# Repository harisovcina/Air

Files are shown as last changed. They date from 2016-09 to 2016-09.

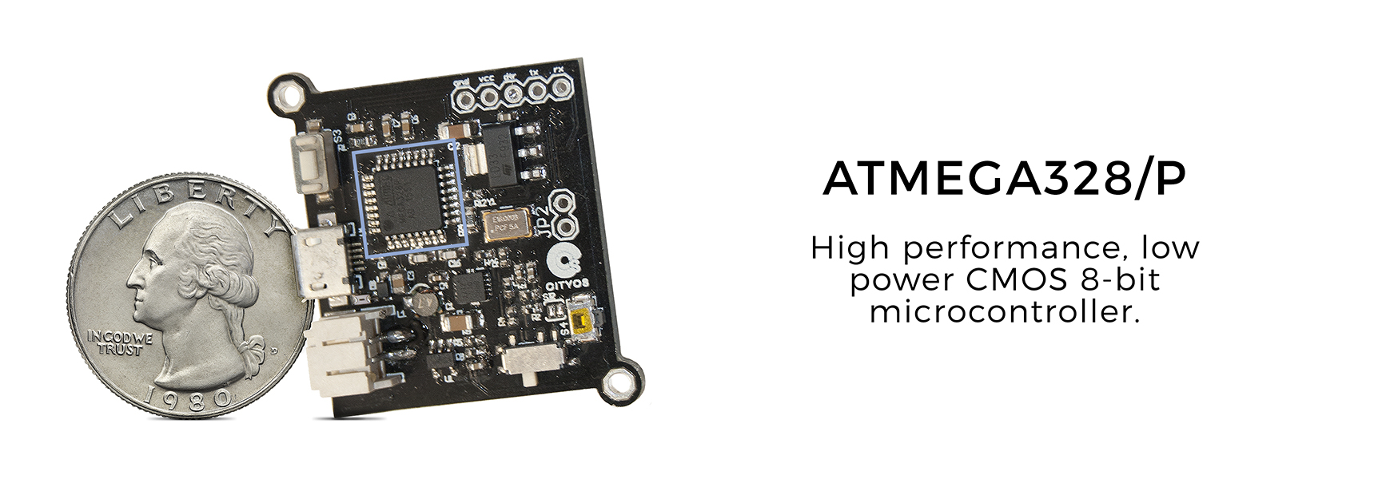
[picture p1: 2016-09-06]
Hardware/Wiki/CPU_back.jpg

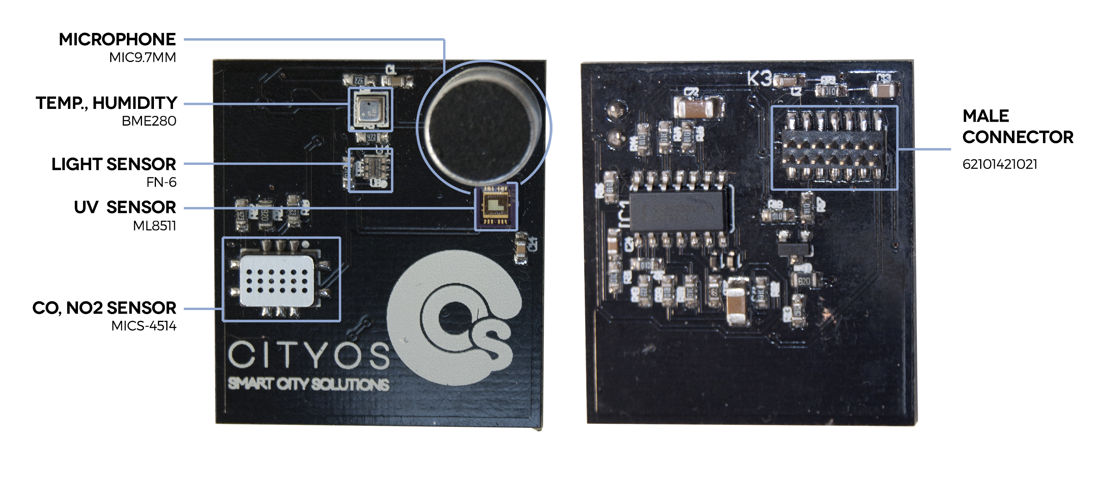
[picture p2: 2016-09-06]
Hardware/Sensor Board/sensor board.jpg

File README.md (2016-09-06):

# CityOSAir

W**elcome to the CityOSAir github!**



Thank you for your interest in creating your own CityOSAir device. In order to join the clean air movement, we will walk you through this step-by-step guide on creating your own device.

Here you will learn how to create your own circuit board or order already made ones, how and where to get an enclosure for the device and, finally, how to setup your new device.

To help spread clean air everywhere, we are giving away all of our code as open source software and hardware. We invite all developers to collaborate and build upon our project. 
Everything you need to get started and become a part of our global movement is listed below.

## Getting started

* [Ordering your board](https://github.com/appsmonkey/CityOSAir/wiki/Board)

* [3D printing your enclosure] (https://github.com/appsmonkey/CityOSAir/wiki/Enclosure)

* [Setting up the device] (https://github.com/appsmonkey/CityOSAir/wiki/Setup)

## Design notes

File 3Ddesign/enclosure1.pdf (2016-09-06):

### 1.Mainboard+sensorboard

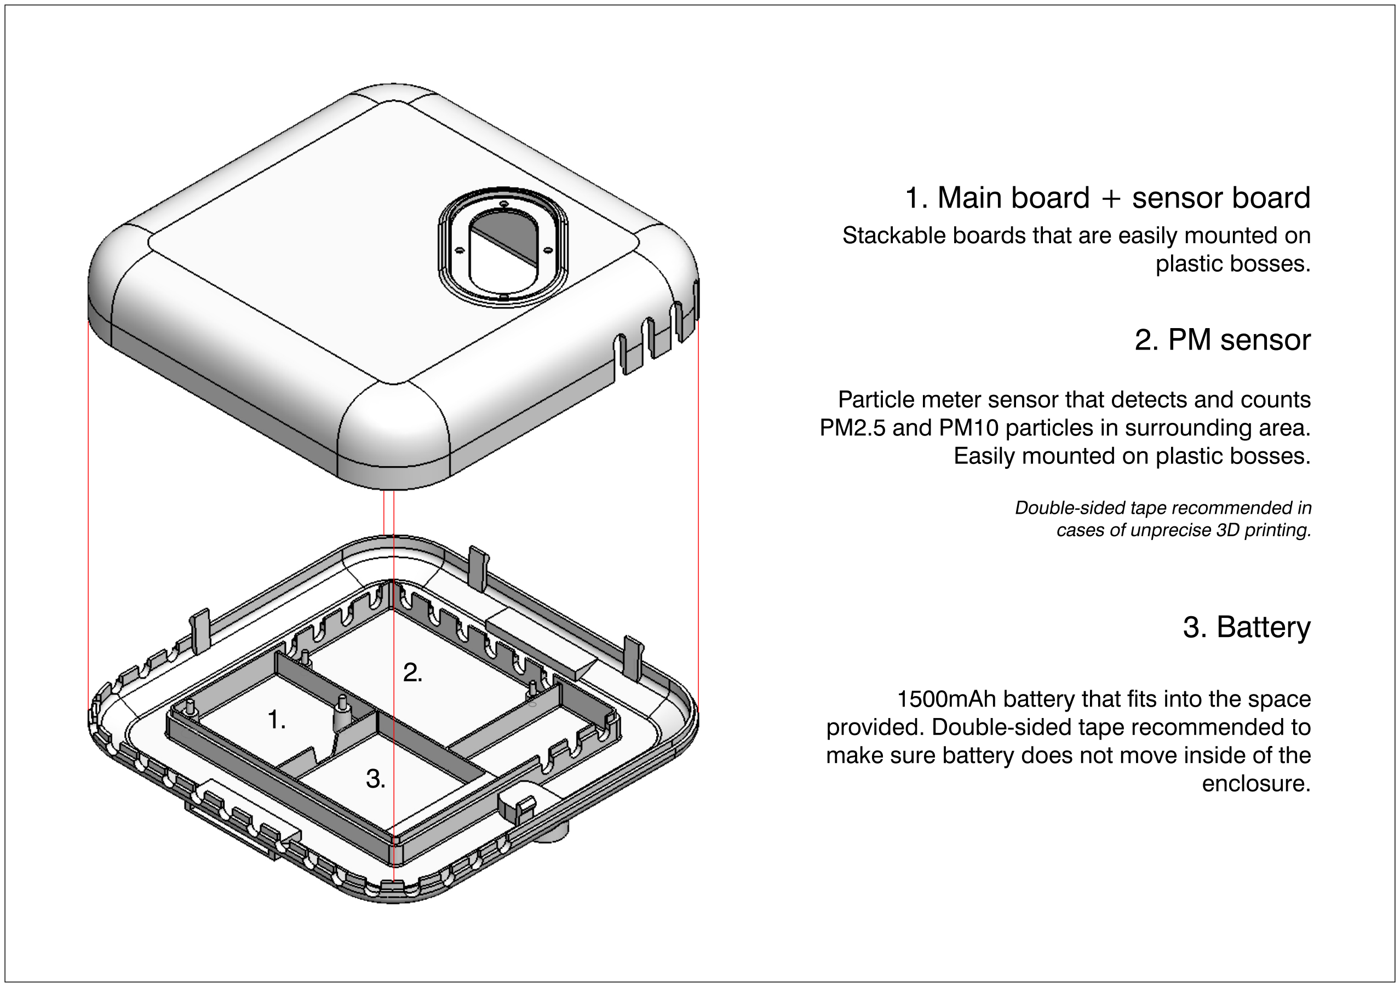
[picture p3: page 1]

1.

2.

3.

### 2.PMsensor

### 3.Battery

Stackableboardsthatareeasilymountedon plasticbosses.

1500mAhbatterythatfitsintothespace provided.Double-sidedtaperecommendedto makesurebatterydoesnotmoveinsideofthe enclosure.

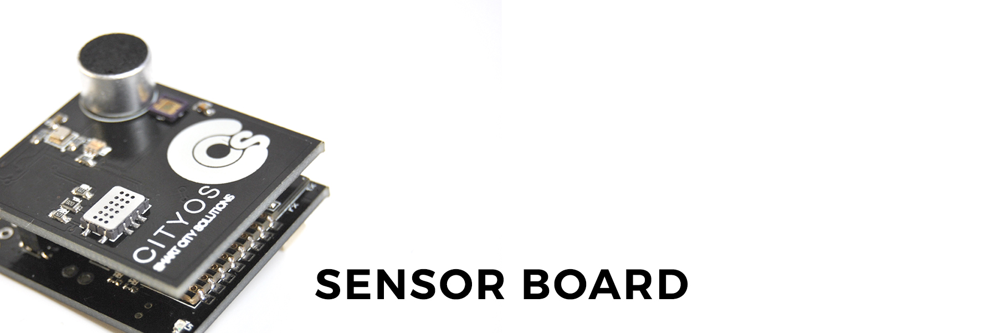
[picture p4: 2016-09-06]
Hardware/Wiki/Header-pic/sensorboard_header.jpg

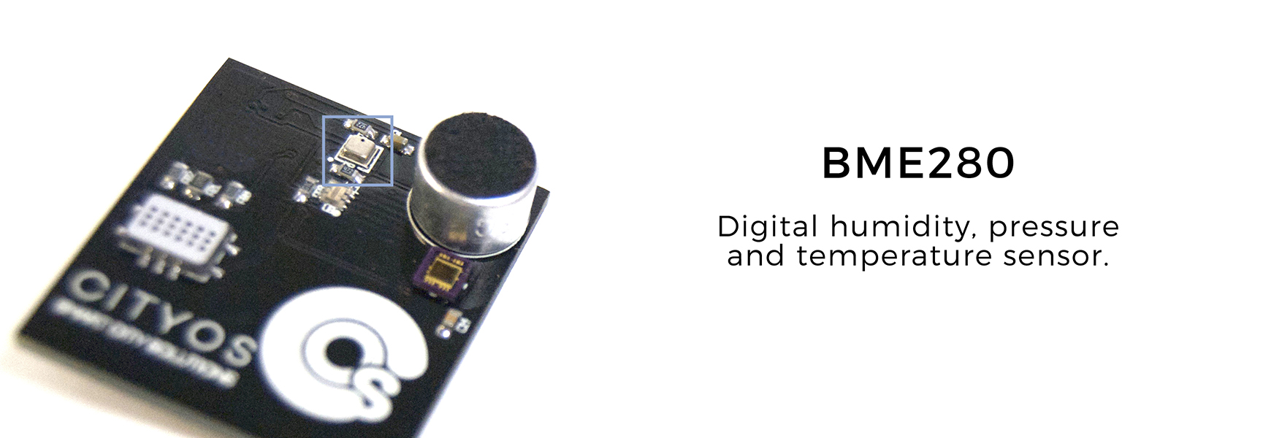
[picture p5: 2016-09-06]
Hardware/Wiki/temp_humid_back.jpg

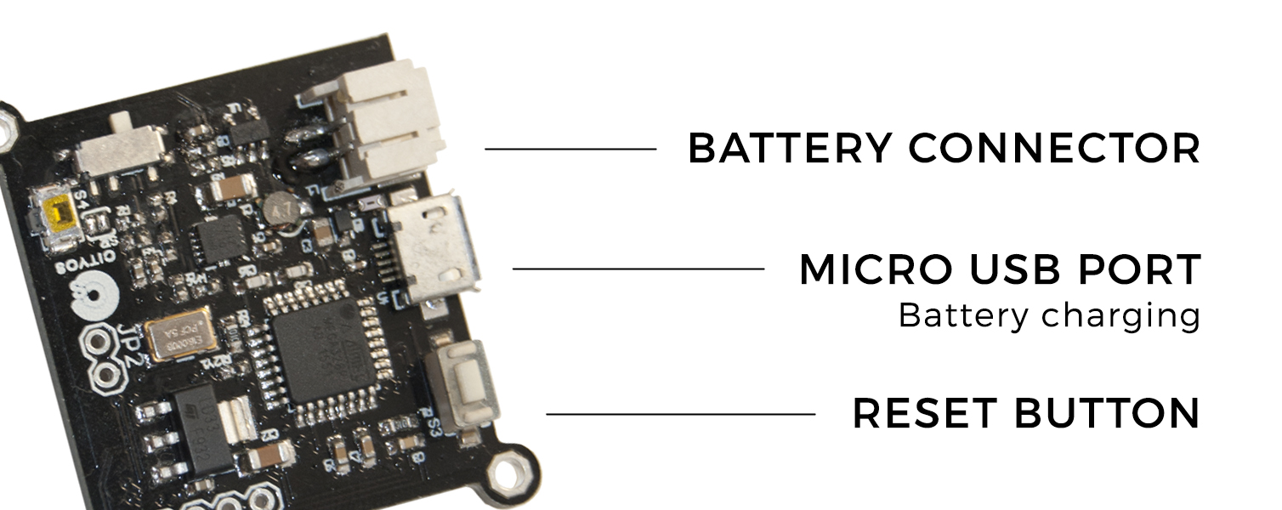
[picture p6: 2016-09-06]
Hardware/Wiki/battery_usb_header.jpg

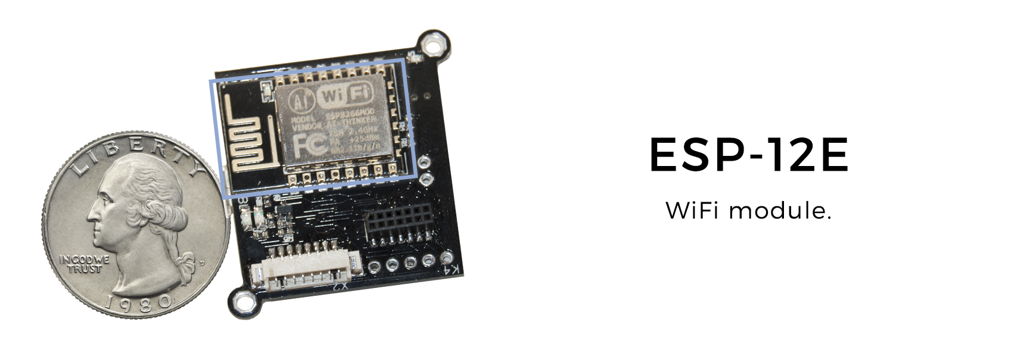
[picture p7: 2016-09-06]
Hardware/Wiki/esp_back.jpg

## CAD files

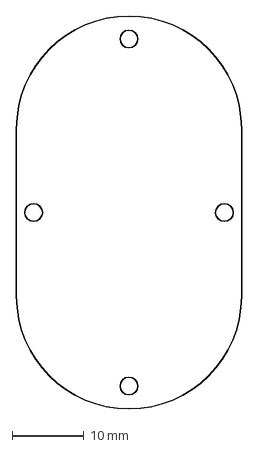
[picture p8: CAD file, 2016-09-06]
3Ddesign/pleksi1.dxf
31.4 x 54.8 mm

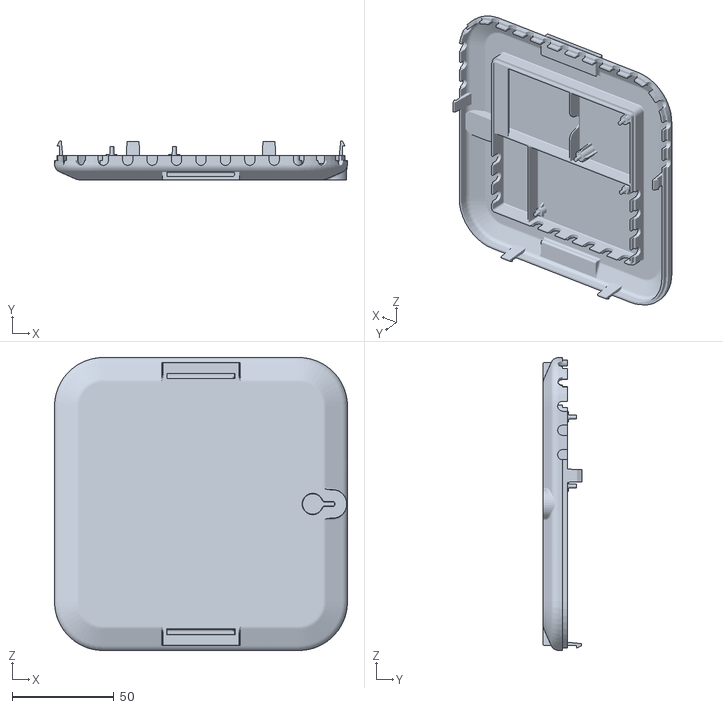
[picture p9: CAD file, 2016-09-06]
3Ddesign/BottomPart1.STL
144.0 x 19.0 x 144.0

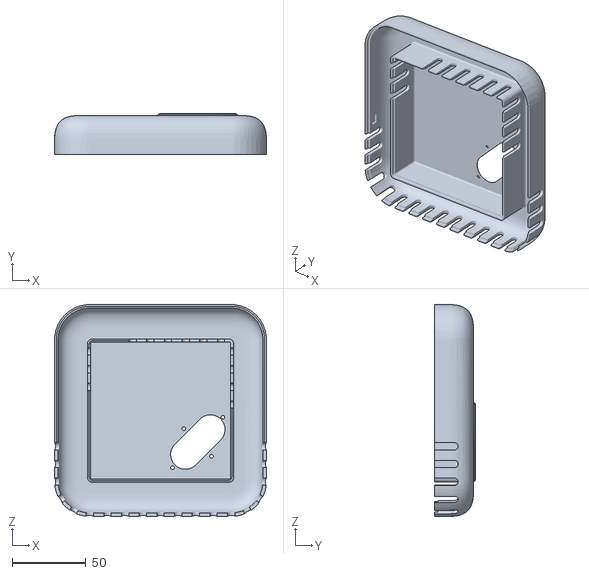
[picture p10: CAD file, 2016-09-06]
3Ddesign/NewTopPart1.STL
144.0 x 27.6 x 144.0

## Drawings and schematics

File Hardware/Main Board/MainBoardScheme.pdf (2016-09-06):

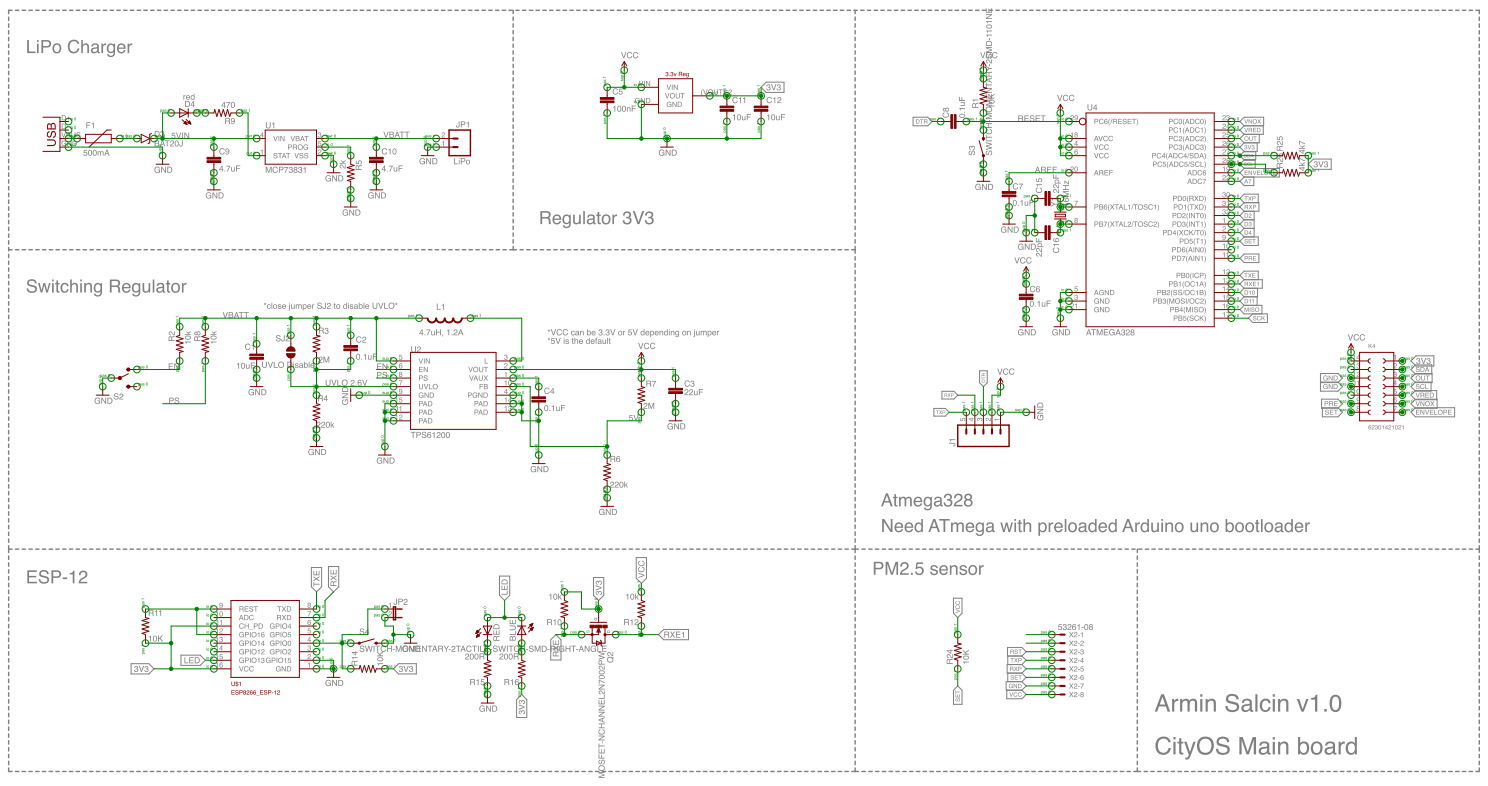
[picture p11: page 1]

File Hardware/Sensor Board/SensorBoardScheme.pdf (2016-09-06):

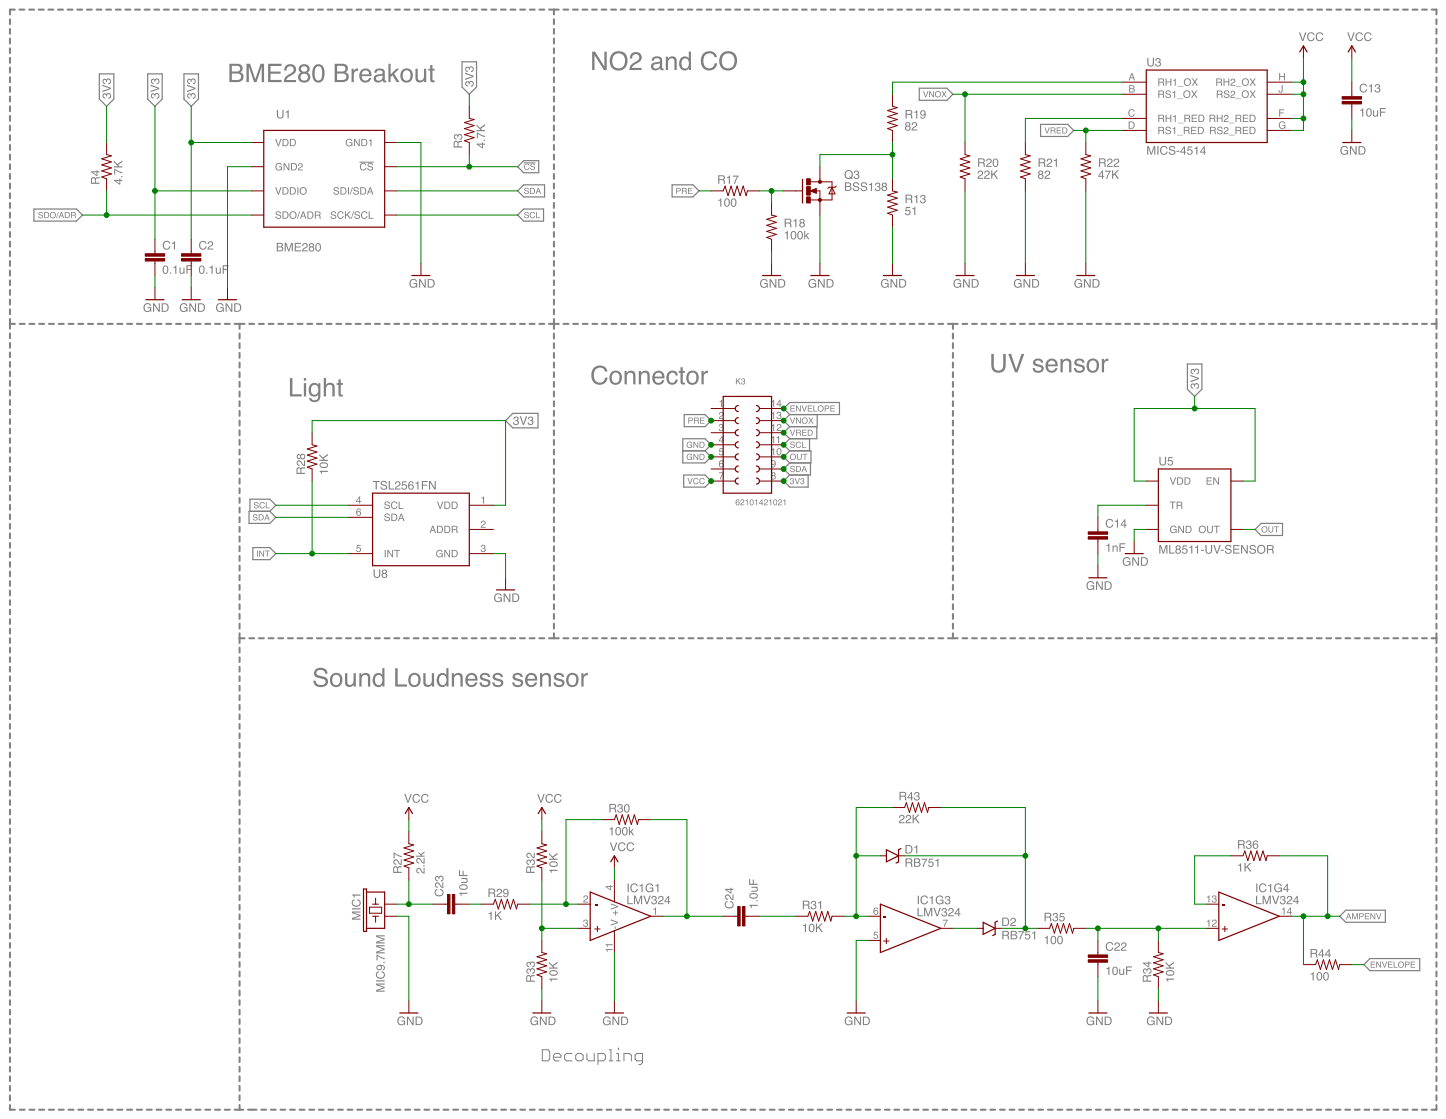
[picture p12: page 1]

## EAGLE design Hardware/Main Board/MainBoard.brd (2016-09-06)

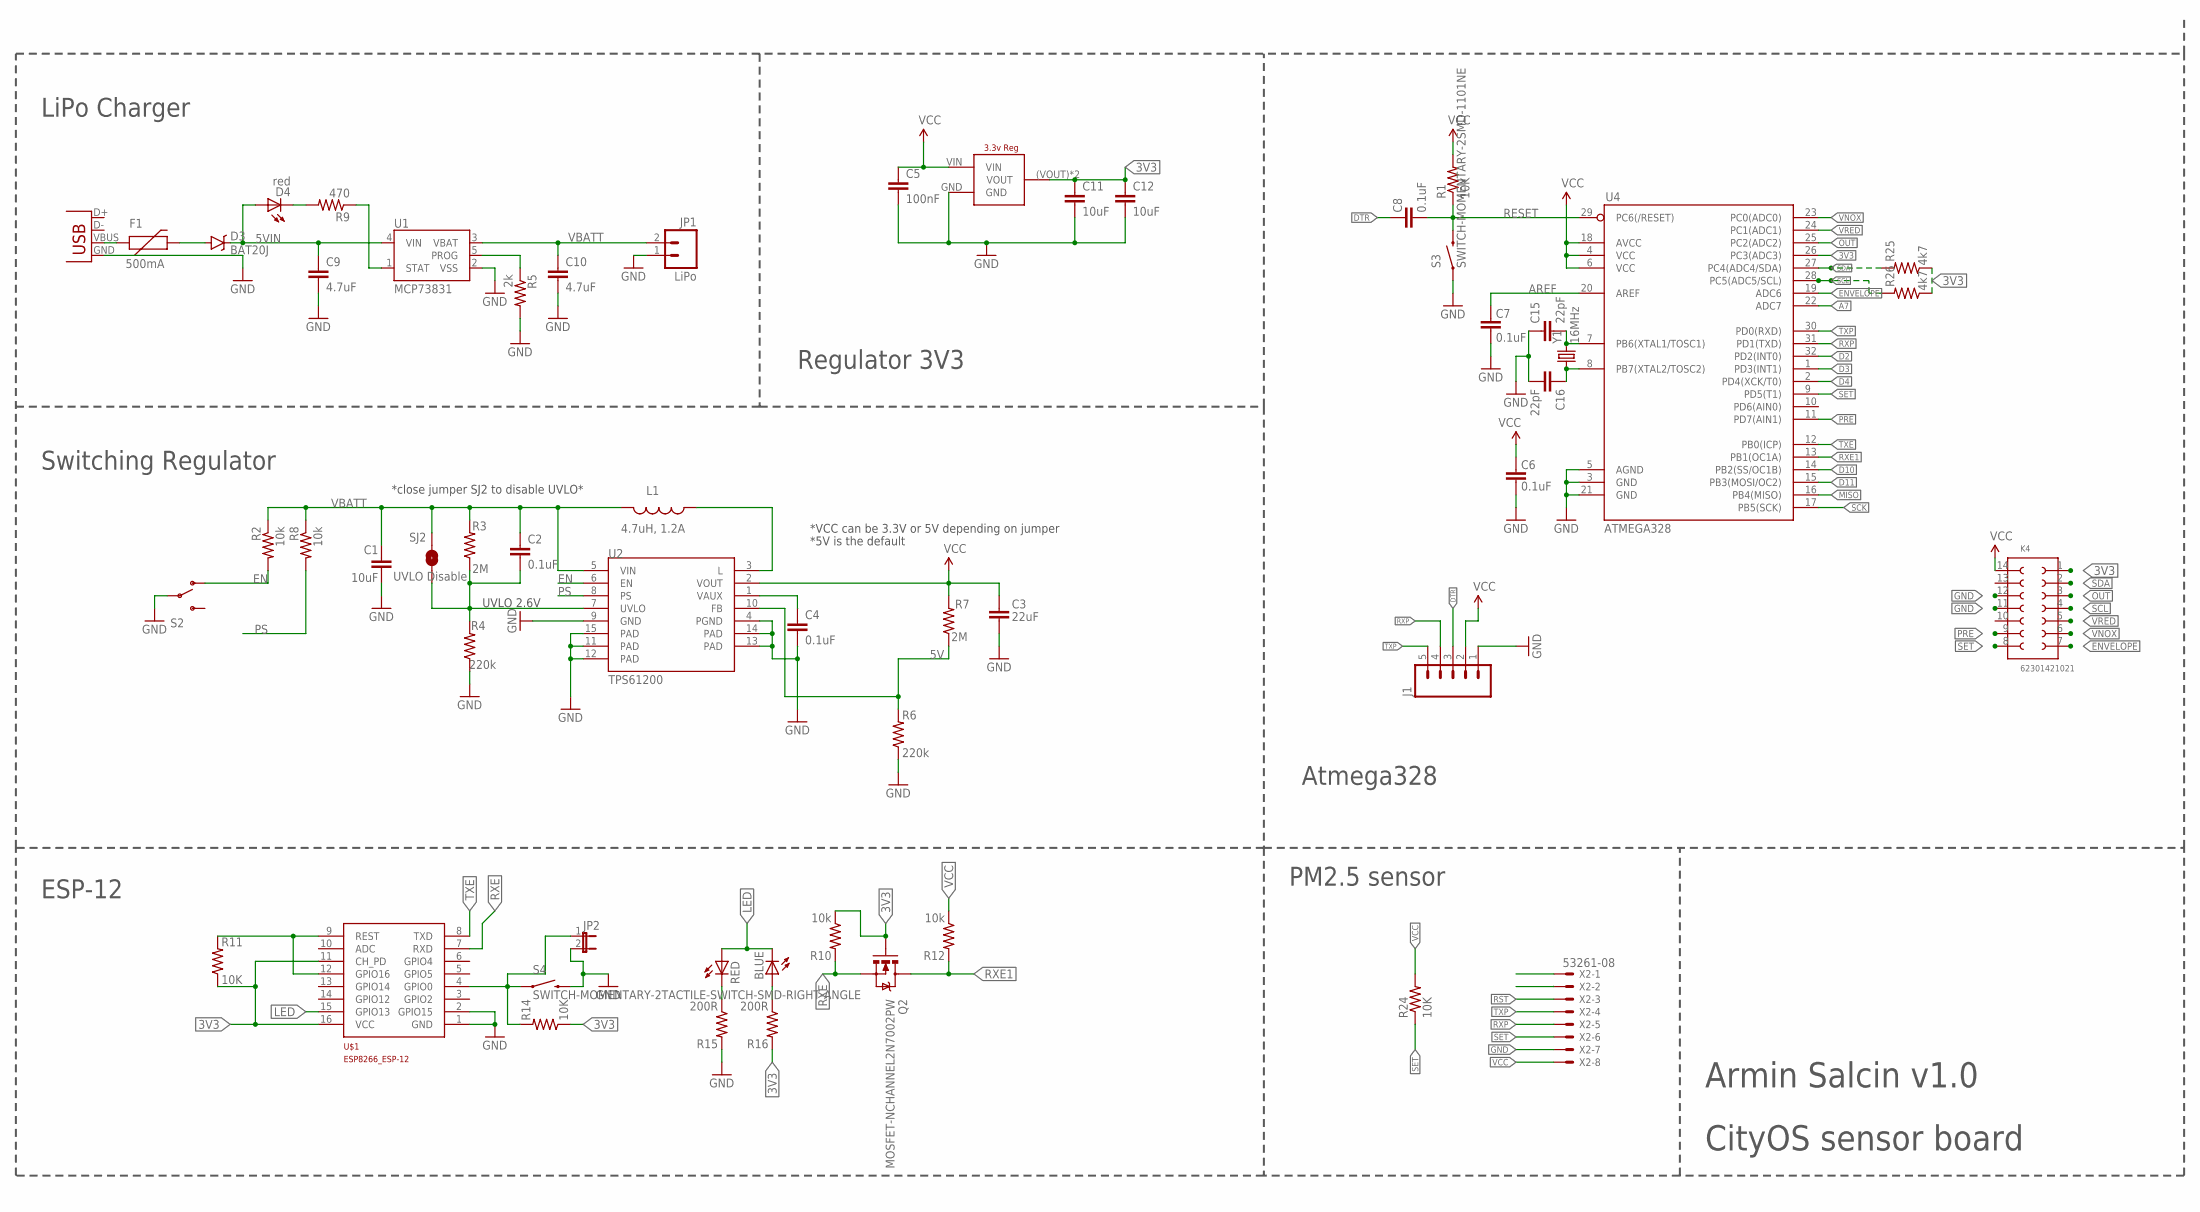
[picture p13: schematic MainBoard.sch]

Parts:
BLUE: LEDCHIPLED_0805; CHIPLED_0805
C1, C12: 10uF; 1206
C2, C4: 0.1uF; 0402-CAP
C3: 22uF; 0805
C5: 100nF; 0402-CAP
C6, C7, C8: 0.1uF; 0603-CAP
C9, C10: 4.7uF; 0402-CAP
C11: 10uF; 0402-CAP
C15, C16: 22pF; 0603-CAP
D3: BAT20J; SOD-323
D4: red; LED-0603
F1: 500mA; 0603
J1: M05PTH; 1X05
JP1: LiPo; JST-2-SMD
JP2: JUMPER-2PTH; 1X02
K4: 62301421021
L1: 4.7uH, 1.2A; CDRH2D09
Q2: MOSFET-NCHANNEL2N7002PW; SOT323
R1, R24: 10K; 0603-RES
R2, R8, R10, R12: 10k; 0402-RES
R3, R7: 2M; 0402-RES
R4, R6: 220k; 0402-RES
R5: 2k; 0402-RES
R9: 470; 0402-RES
R11, R14: 10K; 0402-RES
R15, R16: 200R; 0402-RES
R25, R26: 4k7; 0402-RES
RED: LEDCHIPLED_0805; CHIPLED_0805
S2: SWITCH-SPDT-SMD-A; SWITCH-SPST-SMD-A
S3: SWITCH-MOMENTARY-2SMD-1101NE; TACTILE-SWITCH-1101NE
S4: SWITCH-MOMENTARY-2TACTILE-SWITCH-SMD-RIGHT-ANGLE; TACTILE_SWITCH-SMD-RIGHT-ANGLE
SJ2: UVLO Disable; SJ_2S-NO
U1: MCP73831; SOT23-5
U2: TPS61200; QFN-10_PAD
U4: ATMEGA328; TQFP32-08
U$1: ESP8266_ESP-12; ESP8266-ESP12
U$2: LD1117; LD1117SOT-223
X1: USB-MICROB
X2: 53261-08
Y1: 16MHz; CRYSTAL-SMD-5X3

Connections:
3V3: C11.1, C12.1, K4.1, Q2.1 (G), R10.1, R11.1, R14.1, R16.2, R25.1, R26.1, U4.26 (PC3(ADC3)), U$1.11 (CH_PD), U$1.16 (VCC), U$2.(VOUT) (VOUT), U$2.VOUT
5V: R6.2, R7.1, U2.10 (FB)
5VIN: C9.1, D3.C, D4.A, U1.4 (VIN)
A7: U4.22 (ADC7)
AREF: C7.2, U4.20 (AREF)
D2: U4.32 (PD2(INT0))
D3: U4.1 (PD3(INT1))
D4: U4.2 (PD4(XCK/T0))
D10: U4.14 (PB2(SS/OC1B))
D11: U4.15 (PB3(MOSI/OC2))
DTR: C8.2, J1.3
EN: R2.2, S2.1 (O), U2.6 (EN)
ENVELOPE: K4.7, U4.19 (ADC6)
GND: C1.2, C3.2, C4.2, C5.2, C6.1, C7.1, C9.2, C10.2, C11.2, C12.2, C15.1, C16.2, J1.1, JP1.1, JP2.2, K4.11, K4.12, R4.1, R5.2, R6.1, R15.2, S2.2, S3.1, S4.2, U1.2 (VSS), U2.4 (PGND), U2.9 (GND), U2.11 (PAD), U2.12 (PAD), U2.13 (PAD), U2.14 (PAD), U2.15 (PAD), U4.3 (GND), U4.5 (AGND), U4.21 (GND), U$1.1 (GND), U$1.2 (GPIO15), U$2.GND, X1.GND, X2.7
LED: BLUE.C, RED.A, U$1.15 (GPIO13)
MISO: U4.16 (PB4(MISO))
unnamed: C4.1, U2.1 (VAUX)
unnamed: L1.P$1 (1), U2.3 (L)
unnamed: C16.1, U4.8 (PB7(XTAL2/TOSC2)), Y1.1
unnamed: C15.2, U4.7 (PB6(XTAL1/TOSC1)), Y1.3 (2)
unnamed: JP2.1, R14.2, S4.1, U$1.4 (GPIO0)
unnamed: R11.2, U$1.9 (REST), U$1.12 (GPIO16)
unnamed: F1.1, X1.VBUS
unnamed: D4.C, R9.2
unnamed: R15.1, RED.C
unnamed: BLUE.A, R16.1
unnamed: R5.1, U1.5 (PROG)
unnamed: D3.A, F1.2
unnamed: R9.1, U1.1 (STAT)
OUT: K4.3, U4.25 (PC2(ADC2))
PRE: K4.9, U4.11 (PD7(AIN1))
PS: R8.2, U2.8 (PS)
RESET: C8.1, R1.1, S3.2, U4.29 (PC6(/RESET))
RST: X2.3
RXE: Q2.2 (S), R10.2, U$1.7 (RXD)
RXE1: Q2.3 (D), R12.2, U4.13 (PB1(OC1A))
RXP: J1.4, U4.31 (PD1(TXD)), X2.5
SCK: U4.17 (PB5(SCK))
SCL: K4.4, R26.2, U4.28 (PC5(ADC5/SCL))
SDA: K4.2, R25.2, U4.27 (PC4(ADC4/SDA))
SET: K4.8, R24.1, U4.9 (PD5(T1)), X2.6
TXE: U4.12 (PB0(ICP)), U$1.8 (TXD)
TXP: J1.5, U4.30 (PD0(RXD)), X2.4
UVLO: C2.2, R3.1, R4.2, SJ2.1, U2.7 (UVLO)
VBATT: C1.1, C2.1, C10.1, JP1.2, L1.P$2 (2), R2.1, R3.2, R8.1, SJ2.2, U1.3 (VBAT), U2.5 (VIN)
VCC: C3.1, C5.1, C6.2, J1.2, K4.14, R1.2, R7.2, R12.1, R24.2, U2.2 (VOUT), U4.4 (VCC), U4.6 (VCC), U4.18 (AVCC), U$2.VIN, X2.8
VNOX: K4.6, U4.23 (PC0(ADC0))
VRED: K4.5, U4.24 (PC1(ADC1))

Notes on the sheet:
UVLO 2.6V
*close jumper SJ2 to disable UVLO*
LiPo Charger
Switching Regulator
*VCC can be 3.3V or 5V depending on jumper
*5V is the default
Regulator 3V3
ESP-12
Atmega328
PM2.5 sensor
Armin Salcin v1.0
CityOS sensor board

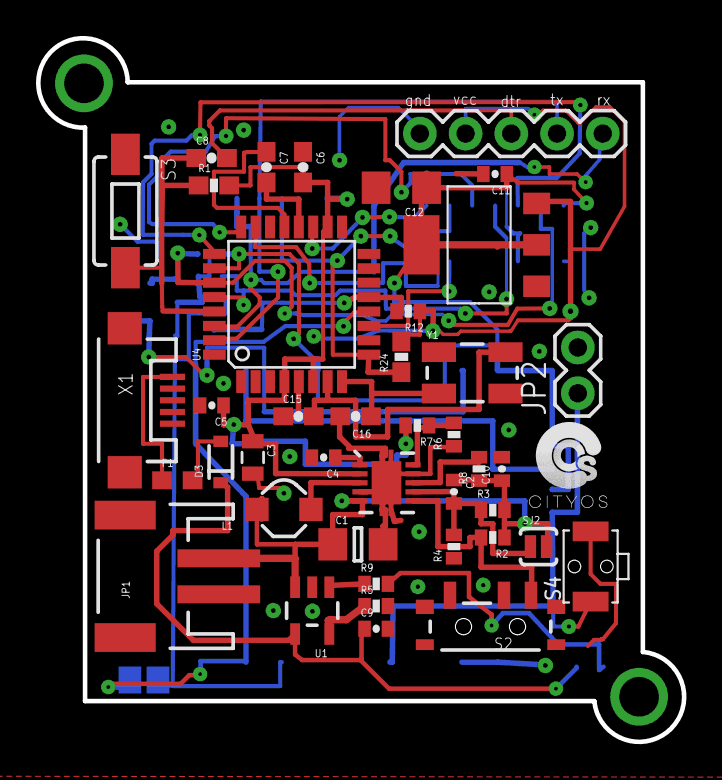
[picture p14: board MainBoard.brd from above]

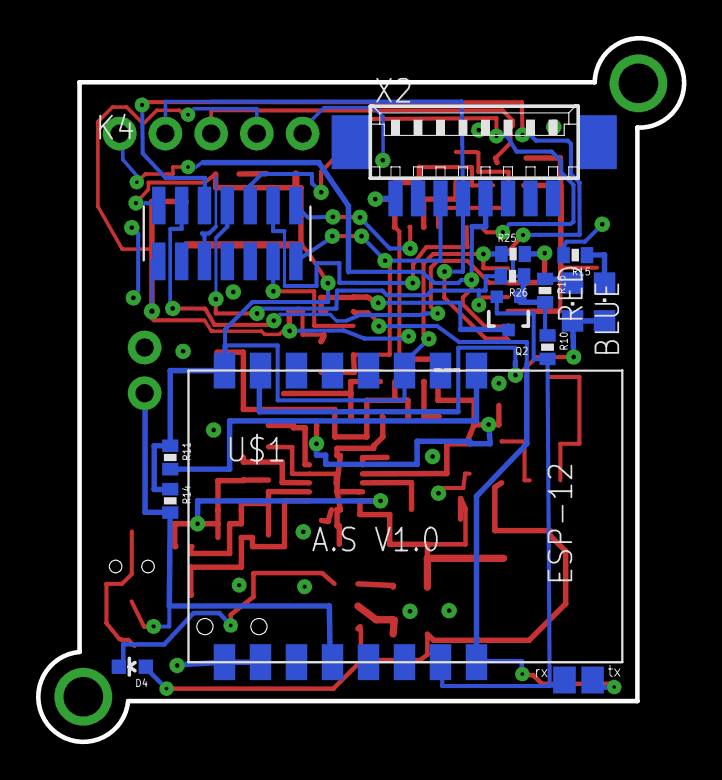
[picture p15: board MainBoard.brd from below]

Board: 2 copper layers, 35.9 x 39.1 mm, 55 parts (14 on the bottom side), 39 nets.

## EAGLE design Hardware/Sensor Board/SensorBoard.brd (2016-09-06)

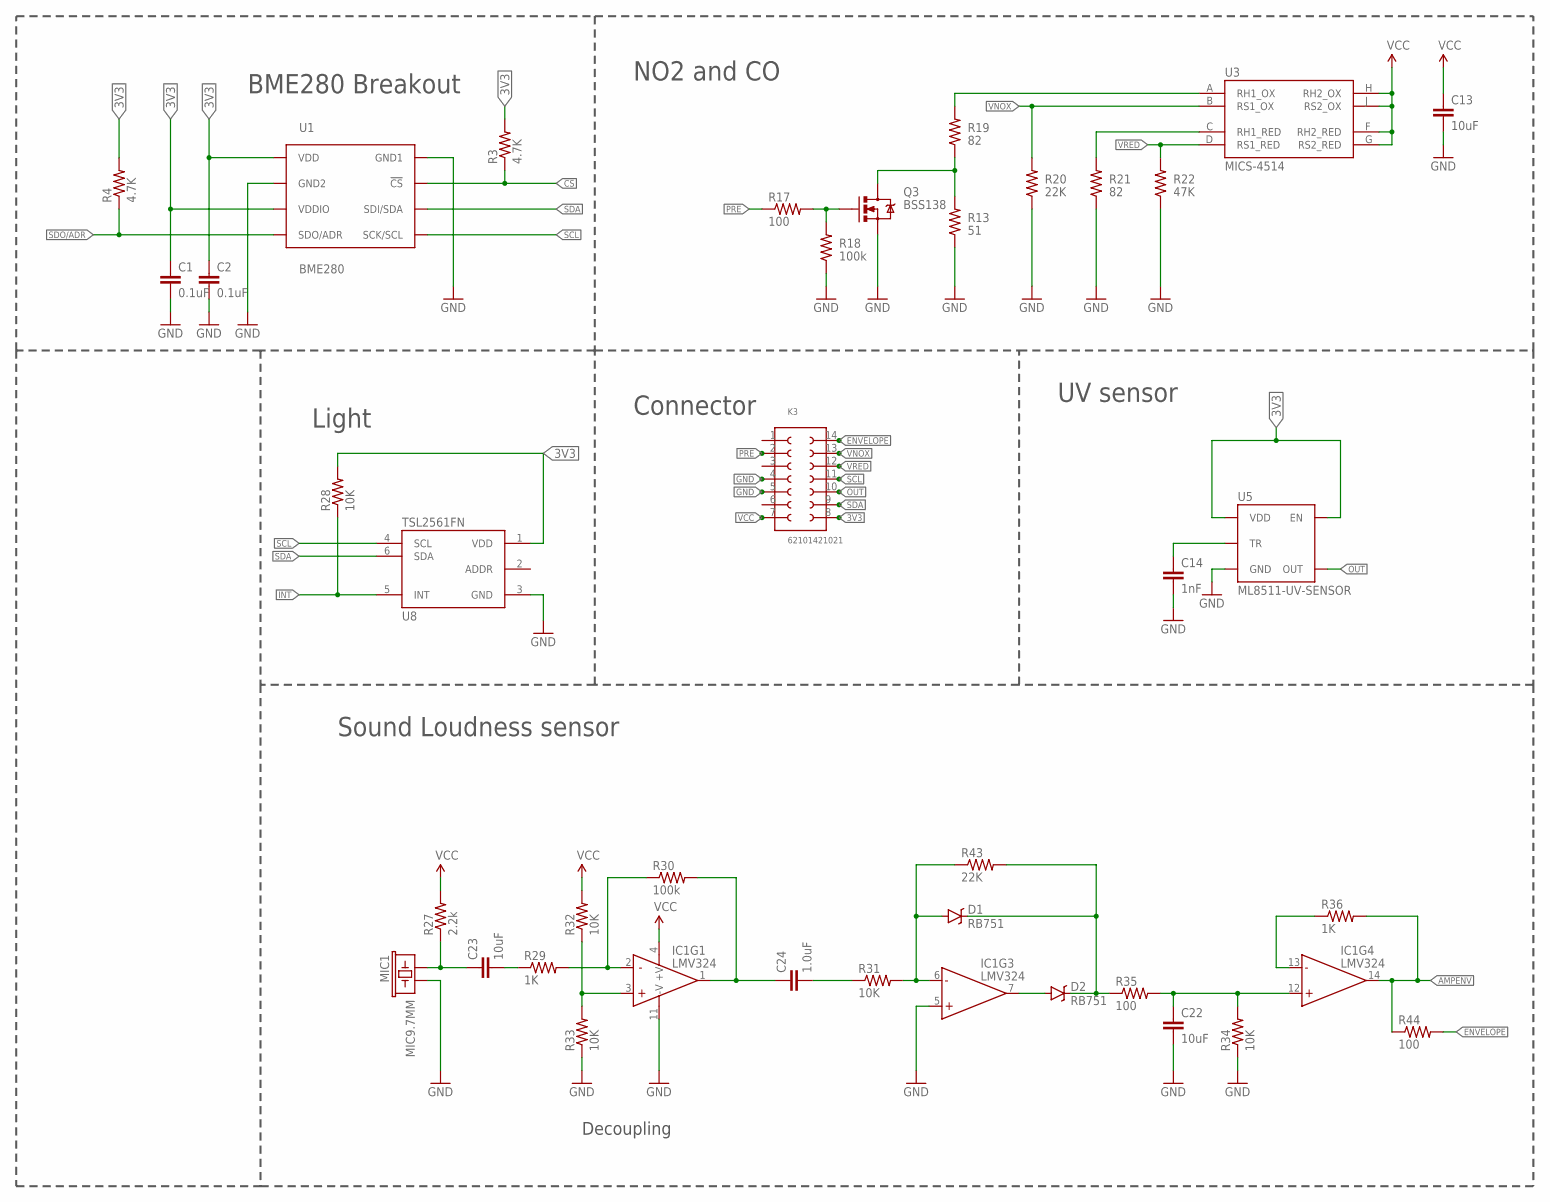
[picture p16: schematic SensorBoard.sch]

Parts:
C1, C2: 0.1uF; 0603-CAP
C13: 10uF; 0805
C14: 1nF; 0603-CAP
C22, C23: 10uF; 1206
C24: 1.0uF; 0603-CAP
D1, D2: RB751; SOD-523
IC1: LMV324; SO014
K3: 62101421021
MIC1: MIC9.7MM; MIC-9.7MM
Q3: MOSFET-NCHANNELBSS138; SOT23-3
R3, R4: 4.7K; 0603-RES
R13: 51; 0603-RES
R17, R35, R44: 100; 0603-RES
R18, R30: 100k; 0603-RES
R19, R21: 82; 0805
R20, R43: 22K; 0603-RES
R22: 47K; 0603-RES
R27: 2.2k; 0603-RES
R28, R31, R32, R33, R34: 10K; 0603-RES
R29, R36: 1K; 0603-RES
U1: BME280; BME280_LGA
U3: MICS-4514; MICS_10-SMD
U5: ML8511-UV-SENSOR; ML8511
U8: TSL2561FN; FN-6

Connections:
3V3: C1.1, C2.1, C13.1, K3.8, R3.2, R4.2, R28.2, U1.P$6 (VDDIO), U1.P$8 (VDD), U3.F (RH2_RED), U3.G (RS2_RED), U3.H (RH2_OX), U3.J (RS2_OX), U5.4 (EN), U5.7 (VDD), U8.1 (VDD)
!CS: R3.1, U1.P$2 (!CS)
AMPENV: IC1.14 (OUT), R36.2, R44.1
ENVELOPE: K3.14, R44.2
GND: C1.2, C2.2, C13.2, C14.2, C22.2, IC1.5 (+IN), IC1.11 (-V), K3.4, K3.5, MIC1.2, Q3.2 (S), R13.1, R18.1, R20.1, R21.1, R22.1, R33.1, R34.1, U1.P$1 (GND1), U1.P$7 (GND2), U5.5 (GND), U8.3 (GND)
INT: R28.1, U8.5 (INT)
N$: C24.1, IC1.1 (OUT), R30.2
unnamed: Q3.3 (D), R13.2, R19.1
unnamed: Q3.1 (G), R17.2, R18.2
unnamed: R19.2, U3.A (RH1_OX)
unnamed: R21.2, U3.C (RH1_RED)
unnamed: C14.1, U5.10 (TR)
unnamed: C23.1, MIC1.1, R27.1
unnamed: IC1.3 (+IN), R32.1, R33.2
unnamed: IC1.2 (-IN), R29.2, R30.1
unnamed: C23.2, R29.1
unnamed: C24.2, R31.1
unnamed: D1.A, IC1.6 (-IN), R31.2, R43.1
unnamed: D2.A, IC1.7 (OUT)
unnamed: D1.C, D2.C, R35.1, R43.2
unnamed: C22.1, IC1.12 (+IN), R34.2, R35.2
unnamed: IC1.13 (-IN), R36.1
OUT: K3.10, U5.8 (OUT)
PRE: K3.2, R17.1
SCL: K3.11, U1.P$4 (SCK/SCL), U8.4 (SCL)
SDA: K3.9, U1.P$3 (SDI/SDA), U8.6 (SDA)
SDO/ADR: R4.1, U1.P$5 (SDO/ADR)
VCC: IC1.4 (+V), K3.7, R27.2, R32.2
VNOX: K3.13, R20.2, U3.B (RS1_OX)
VRED: K3.12, R22.2, U3.D (RS1_RED)

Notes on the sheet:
NO2 and CO
UV sensor
Light
Decoupling
BME280 Breakout
Sound Loudness sensor
Connector

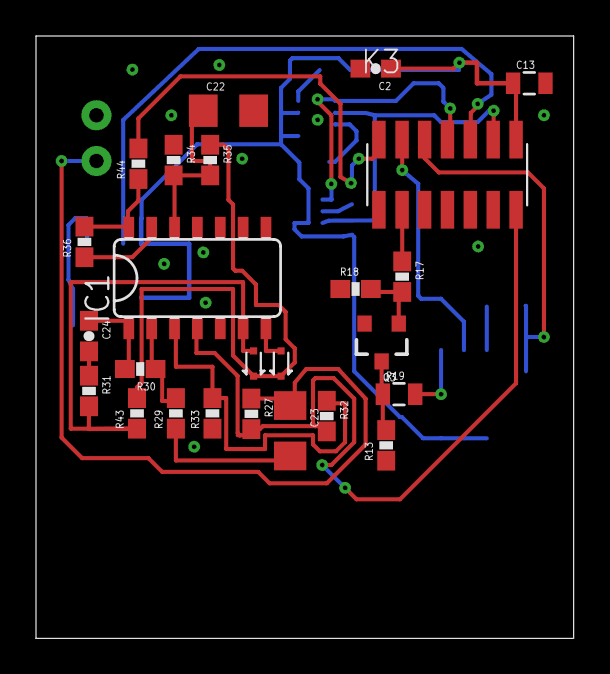
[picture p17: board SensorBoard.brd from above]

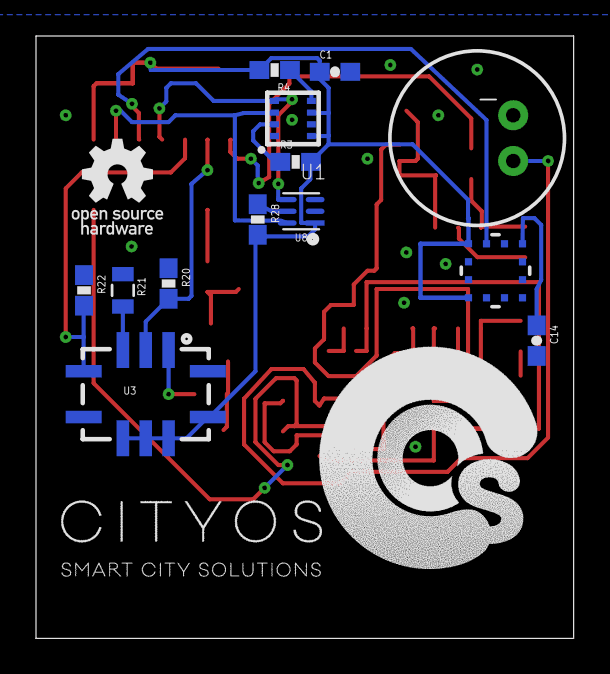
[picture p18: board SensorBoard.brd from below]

Board: 2 copper layers, 29.9 x 33.5 mm, 38 parts (13 on the bottom side), 30 nets.

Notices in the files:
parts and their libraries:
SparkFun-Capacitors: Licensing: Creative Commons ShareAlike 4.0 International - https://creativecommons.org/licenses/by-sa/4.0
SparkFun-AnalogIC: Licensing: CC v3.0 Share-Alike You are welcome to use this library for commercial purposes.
